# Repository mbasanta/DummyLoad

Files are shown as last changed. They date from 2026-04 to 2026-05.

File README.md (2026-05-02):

# DummyLoad

KiCad project for a 50 ohm RF dummy load board with integrated attenuation and rectified measurement output.

## Overview

This repository contains the schematic, PCB, custom footprint library, and generated manufacturing artifacts for the DummyLoad board.

From the schematic title block and notes:
- Design target: 50 ohm dummy load
- Rated power (design intent): 10 W
- Includes attenuation network:
  - Note in schematic: "40db Attenuation (use 3x 261 Ohm resistors for 30db)"
- Includes a rectified voltage measurement point for RF power estimation (see [Dummy Load Voltages](output/Dummy%20Load%20Voltages.pdf) for the relationship between rectified voltage and radio power output)

## Schematic

Schematic

## PCB

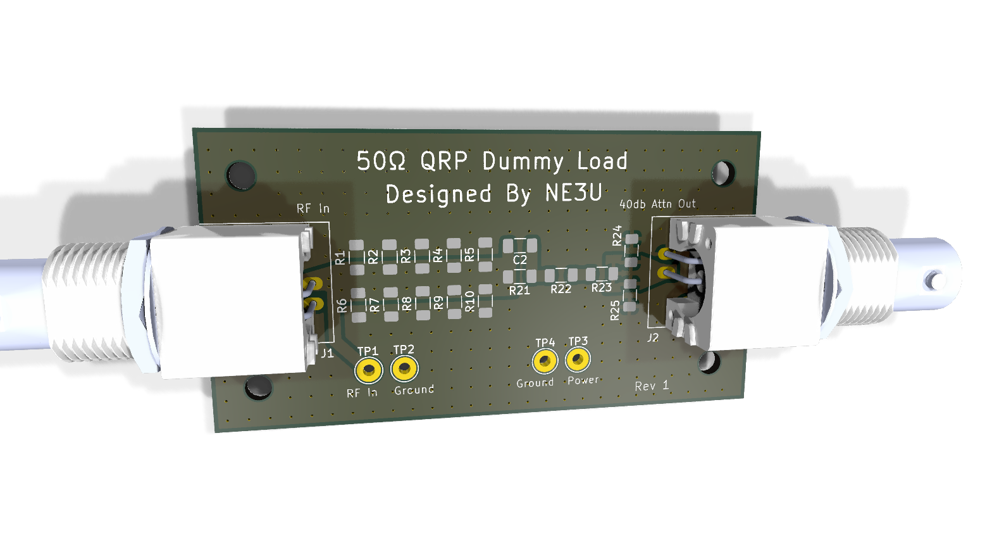
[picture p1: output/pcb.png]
PCB


## Main Files

- `DummyLoad.kicad_sch`: KiCad schematic
- `DummyLoad.kicad_pcb`: KiCad PCB layout
- `DummyLoad.kicad_pro`: KiCad project
- `MiscFootprints.pretty/`: Local footprint library used by this project
- `output/`: Generated artifacts (BOM, schematic PDF, Gerbers, drill files)
- `.github/workflows/kicad.yml`: CI workflow for ERC/DRC and artifact generation

## Connectors and Test Points

- `J1`: RF In (BNC horizontal)
- `J2`: RF Out (BNC horizontal)
- `TP1`: Power Out (rectified measurement output)
- `TP2`: GND

## Bill of Materials

A generated BOM is committed at:
- `output/bom.csv`

The CI workflow exports BOM fields:
- Reference
- Value
- Footprint
- Quantity
- DNP
- Mouser PN
- Datasheet

## Generated Manufacturing Outputs

When CI succeeds, generated files are updated in:
- `output/schematic.pdf`
- `output/bom.csv`
- `output/gerbers/`

These include copper, mask, silkscreen, fab, edge cuts, and drill outputs.

## CI / Automation

GitHub Actions workflow: `.github/workflows/kicad.yml`

It runs on pushes and pull requests to `main` (ignoring changes under `output/**`) and can also be triggered manually.

The workflow performs:
1. KiCad ERC
2. KiCad DRC
3. Schematic PDF export
4. BOM export
5. Gerber and drill export
6. Commit updated generated outputs on `main`
7. Upload production artifacts

## Working With the Project Locally

1. Open `DummyLoad.kicad_pro` in KiCad.
2. Ensure the local footprint library is available:
   - `MiscFootprints.pretty`
3. Run:
   - Schematic Editor ERC
   - PCB Editor DRC
4. Generate fabrication outputs from KiCad if needed.

## Safety and Validation Notes

This project handles RF power dissipation. Before physical use:
- Verify resistor power dissipation and thermal limits for your operating conditions.
- Validate attenuation and measurement calibration on your target frequency range.
- Confirm connector, PCB copper, and assembly choices meet your power and duty-cycle requirements.

## License

MIT. See `LICENSE`.

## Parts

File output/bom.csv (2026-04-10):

Refs | Value | Footprint | Qty | DNP | Mouser PN | Datasheet
C1 | 10nF | Capacitor_SMD:C_1206_3216Metric_Pad1.33x1.80mm_HandSolder | 1 |  | 77-VJ1206Y103JXAMP | https://www.vishay.com/docs/45199/vjcommercialseries.pdf
C2 | C | Capacitor_SMD:C_1206_3216Metric_Pad1.33x1.80mm_HandSolder | 1 | DNP |  | ~
D1 | 1N5711 | Diode_SMD:Nexperia_CFP3_SOD-123W | 1 |  | 621-1N5711W-F | https://www.mouser.com/datasheet/3/175/1/1N5711W.pdf
J1 | RF In | Connector_Coaxial:BNC_Amphenol_B6252HB-NPP3G-50_Horizontal | 1 |  | 737-RF101KD0050BKHDW | https://www.mouser.com/datasheet/3/6015/1/rf1_01k_d_00_50_bk_hdw_data_sheet.pdf
J2 | RF Out | Connector_Coaxial:BNC_Amphenol_B6252HB-NPP3G-50_Horizontal | 1 |  | 737-RF101KD0050BKHDW | https://www.mouser.com/datasheet/3/6015/1/rf1_01k_d_00_50_bk_hdw_data_sheet.pdf
R1 | 1K | Resistor_SMD:R_1206_3216Metric_Pad1.30x1.75mm_HandSolder | 1 |  | 71-RCS12061K00FKEA | https://www.vishay.com/docs/20065/rcse3.pdf
R2 | 1K | Resistor_SMD:R_1206_3216Metric_Pad1.30x1.75mm_HandSolder | 1 |  | 71-RCS12061K00FKEA | https://www.vishay.com/docs/20065/rcse3.pdf
R3 | 1K | Resistor_SMD:R_1206_3216Metric_Pad1.30x1.75mm_HandSolder | 1 |  | 71-RCS12061K00FKEA | https://www.vishay.com/docs/20065/rcse3.pdf
R4 | 1K | Resistor_SMD:R_1206_3216Metric_Pad1.30x1.75mm_HandSolder | 1 |  | 71-RCS12061K00FKEA | https://www.vishay.com/docs/20065/rcse3.pdf
R5 | 1K | Resistor_SMD:R_1206_3216Metric_Pad1.30x1.75mm_HandSolder | 1 |  | 71-RCS12061K00FKEA | https://www.vishay.com/docs/20065/rcse3.pdf
R6 | 1K | Resistor_SMD:R_1206_3216Metric_Pad1.30x1.75mm_HandSolder | 1 |  | 71-RCS12061K00FKEA | https://www.vishay.com/docs/20065/rcse3.pdf
R7 | 1K | Resistor_SMD:R_1206_3216Metric_Pad1.30x1.75mm_HandSolder | 1 |  | 71-RCS12061K00FKEA | https://www.vishay.com/docs/20065/rcse3.pdf
R8 | 1K | Resistor_SMD:R_1206_3216Metric_Pad1.30x1.75mm_HandSolder | 1 |  | 71-RCS12061K00FKEA | https://www.vishay.com/docs/20065/rcse3.pdf
R9 | 1K | Resistor_SMD:R_1206_3216Metric_Pad1.30x1.75mm_HandSolder | 1 |  | 71-RCS12061K00FKEA | https://www.vishay.com/docs/20065/rcse3.pdf
R10 | 1K | Resistor_SMD:R_1206_3216Metric_Pad1.30x1.75mm_HandSolder | 1 |  | 71-RCS12061K00FKEA | https://www.vishay.com/docs/20065/rcse3.pdf
R11 | 1K | Resistor_SMD:R_1206_3216Metric_Pad1.30x1.75mm_HandSolder | 1 |  | 71-RCS12061K00FKEA | https://www.vishay.com/docs/20065/rcse3.pdf
R12 | 1K | Resistor_SMD:R_1206_3216Metric_Pad1.30x1.75mm_HandSolder | 1 |  | 71-RCS12061K00FKEA | https://www.vishay.com/docs/20065/rcse3.pdf
R13 | 1K | Resistor_SMD:R_1206_3216Metric_Pad1.30x1.75mm_HandSolder | 1 |  | 71-RCS12061K00FKEA | https://www.vishay.com/docs/20065/rcse3.pdf
R14 | 1K | Resistor_SMD:R_1206_3216Metric_Pad1.30x1.75mm_HandSolder | 1 |  | 71-RCS12061K00FKEA | https://www.vishay.com/docs/20065/rcse3.pdf
R15 | 1K | Resistor_SMD:R_1206_3216Metric_Pad1.30x1.75mm_HandSolder | 1 |  | 71-RCS12061K00FKEA | https://www.vishay.com/docs/20065/rcse3.pdf
R16 | 1K | Resistor_SMD:R_1206_3216Metric_Pad1.30x1.75mm_HandSolder | 1 |  | 71-RCS12061K00FKEA | https://www.vishay.com/docs/20065/rcse3.pdf
R17 | 1K | Resistor_SMD:R_1206_3216Metric_Pad1.30x1.75mm_HandSolder | 1 |  | 71-RCS12061K00FKEA | https://www.vishay.com/docs/20065/rcse3.pdf
R18 | 1K | Resistor_SMD:R_1206_3216Metric_Pad1.30x1.75mm_HandSolder | 1 |  | 71-RCS12061K00FKEA | https://www.vishay.com/docs/20065/rcse3.pdf
R19 | 1K | Resistor_SMD:R_1206_3216Metric_Pad1.30x1.75mm_HandSolder | 1 |  | 71-RCS12061K00FKEA | https://www.vishay.com/docs/20065/rcse3.pdf
R20 | 1K | Resistor_SMD:R_1206_3216Metric_Pad1.30x1.75mm_HandSolder | 1 |  | 71-RCS12061K00FKEA | https://www.vishay.com/docs/20065/rcse3.pdf
R21 | 820 | Resistor_SMD:R_1206_3216Metric_Pad1.30x1.75mm_HandSolder | 1 |  | 279-CRGH1206F820R | https://www.te.com/commerce/DocumentDelivery/DDEController?Action=srchrtrv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
R22 | 820 | Resistor_SMD:R_1206_3216Metric_Pad1.30x1.75mm_HandSolder | 1 |  | 279-CRGH1206F820R | https://www.te.com/commerce/DocumentDelivery/DDEController?Action=srchrtrv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
R23 | 820 | Resistor_SMD:R_1206_3216Metric_Pad1.30x1.75mm_HandSolder | 1 |  | 279-CRGH1206F820R | https://www.te.com/commerce/DocumentDelivery/DDEController?Action=srchrtrv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
R24 | 102 | Resistor_SMD:R_1206_3216Metric_Pad1.30x1.75mm_HandSolder | 1 |  | 667-ERJ-8ENF1020V | https://industrial.panasonic.com/cdbs/www-data/pdf/RDO0000/RDO0000C334.pdf
R25 | 102 | Resistor_SMD:R_1206_3216Metric_Pad1.30x1.75mm_HandSolder | 1 |  | 667-ERJ-8ENF1020V | https://industrial.panasonic.com/cdbs/www-data/pdf/RDO0000/RDO0000C334.pdf
R26 | 100K | Resistor_SMD:R_1206_3216Metric_Pad1.30x1.75mm_HandSolder | 1 |  | 652-CRM1206QFX-1003E | https://www.mouser.com/catalog/specsheets/Bourns_1-11-2023_CRM-Q_datasheet.pdf
TP1 | RF In | TestPoint:TestPoint_THTPad_D3.0mm_Drill1.5mm | 1 |  |  | ~
TP2 | GND | TestPoint:TestPoint_THTPad_D3.0mm_Drill1.5mm | 1 |  |  | ~
TP3 | Power Out | TestPoint:TestPoint_THTPad_D3.0mm_Drill1.5mm | 1 |  |  | ~
TP4 | GND | TestPoint:TestPoint_THTPad_D3.0mm_Drill1.5mm | 1 |  |  | ~

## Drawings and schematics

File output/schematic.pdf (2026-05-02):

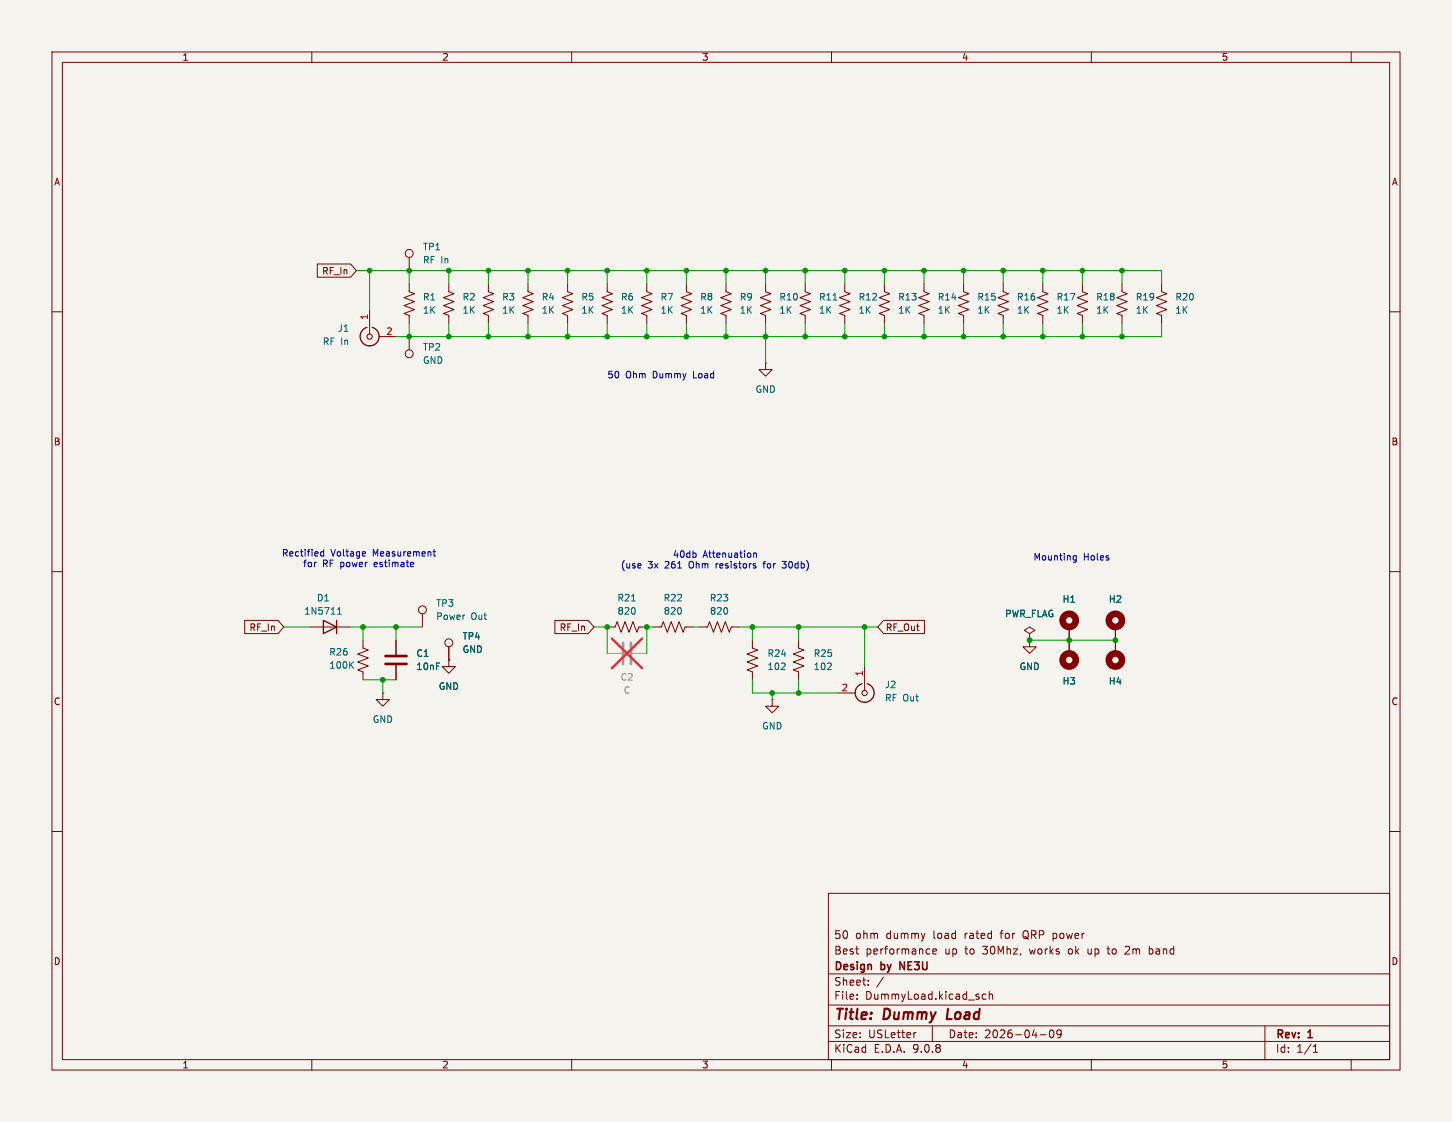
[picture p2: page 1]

for RF power estimate

Id: 1/1 Title: Dummy Load

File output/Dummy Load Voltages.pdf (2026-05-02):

## Dummy Load Power Output

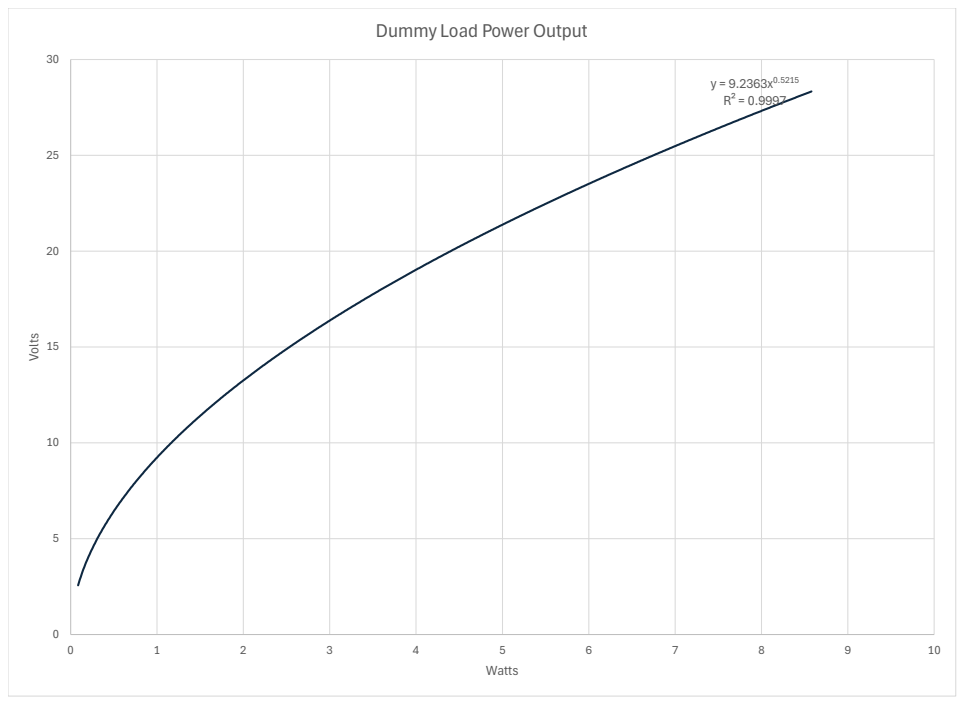
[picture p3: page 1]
Volts; Watts

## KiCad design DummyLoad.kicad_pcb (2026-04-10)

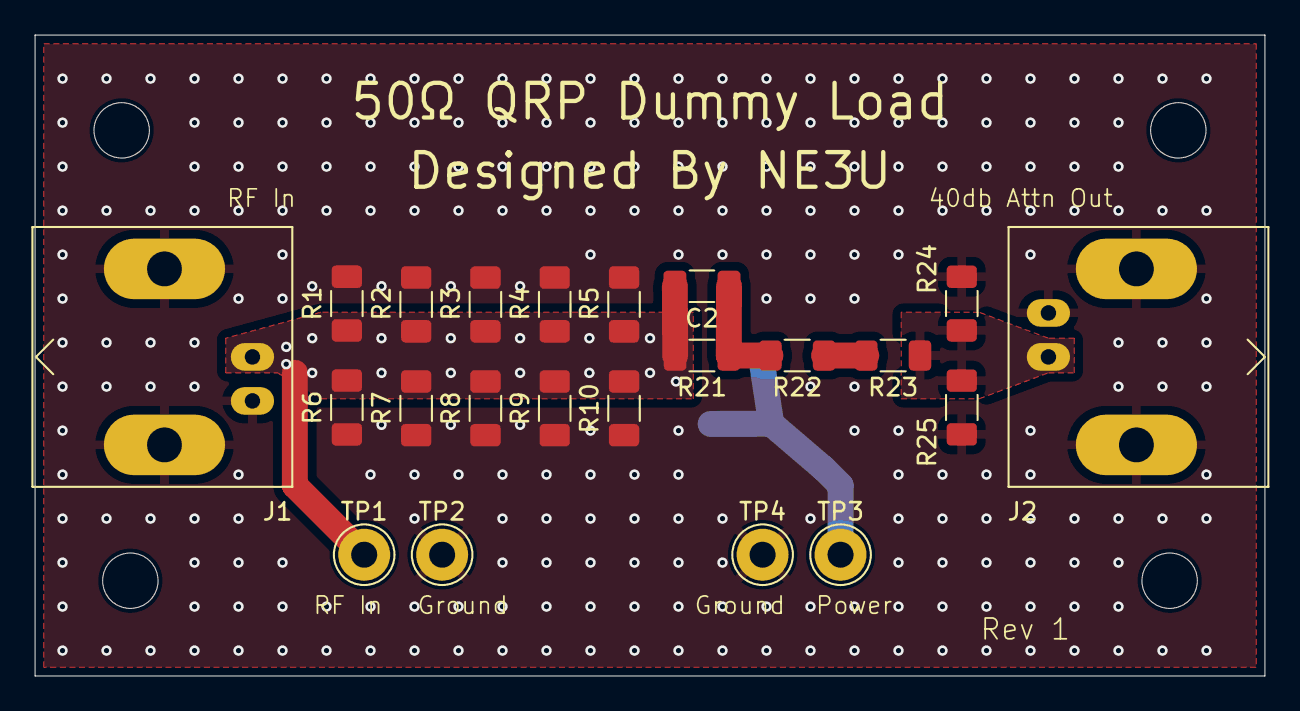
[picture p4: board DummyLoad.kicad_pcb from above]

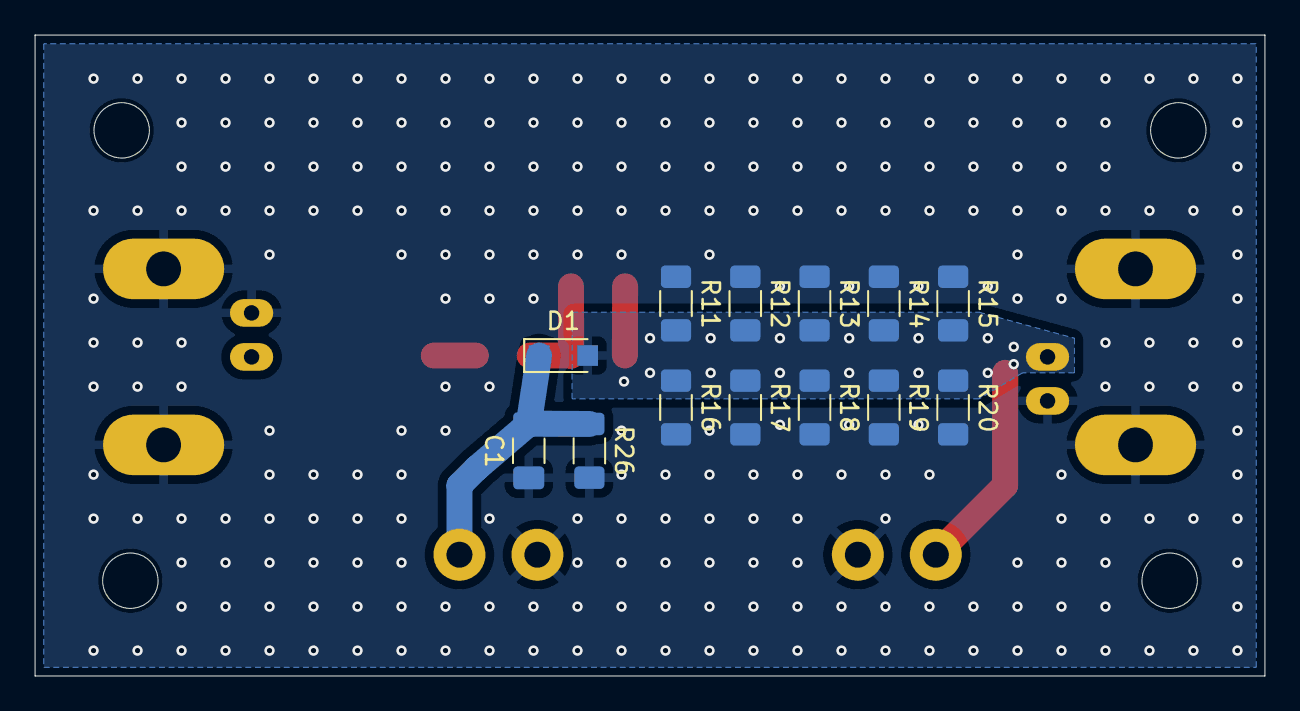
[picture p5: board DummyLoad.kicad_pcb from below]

Board: 2 copper layers, 71.0 x 37.0 mm, 39 parts (13 on the bottom side), 6 nets.

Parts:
C1: 10nF; C_1206_3216Metric_Pad1.33x1.80mm_HandSolder
C2: C; C_1206_3216Metric_Pad1.33x1.80mm_HandSolder
D1: 1N5711; Nexperia_CFP3_SOD-123W
H1, H2, H3, H4: MountingHole_Pad; MountingHole_3.2mm_M3
J1: RF In; BNC_Amphenol_B6252HB-NPP3G-50_Horizontal
J2: RF Out; BNC_Amphenol_B6252HB-NPP3G-50_Horizontal
R1, R2, R3, R4, R5, R6, R7, R8, R9, R10, R11, R12, R13, R14, R15, R16, R17, R18, R19, R20: 1K; R_1206_3216Metric_Pad1.30x1.75mm_HandSolder
R21, R22, R23: 820; R_1206_3216Metric_Pad1.30x1.75mm_HandSolder
R24, R25: 102; R_1206_3216Metric_Pad1.30x1.75mm_HandSolder
R26: 100K; R_1206_3216Metric_Pad1.30x1.75mm_HandSolder
TP1: RF In; TestPoint_THTPad_D3.0mm_Drill1.5mm
TP2, TP4: GND; TestPoint_THTPad_D3.0mm_Drill1.5mm
TP3: Power Out; TestPoint_THTPad_D3.0mm_Drill1.5mm

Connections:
GND: C1.2, J1.2 (Ext), J2.2 (Ext), R1.2, R2.2, R3.2, R4.2, R5.2, R6.2, R7.2, R8.2, R9.2, R10.2, R11.2, R12.2, R13.2, R14.2, R15.2, R16.2, R17.2, R18.2, R19.2, R20.2, R24.2, R25.2, R26.2, TP2.1, TP4.1
unnamed: C2.1, R21.1, R22.2
unnamed: C1.1, D1.1 (K), R26.1, TP3.1
unnamed: R22.1, R23.2
RF_In: C2.2, D1.2 (A), J1.1 (In), R1.1, R2.1, R3.1, R4.1, R5.1, R6.1, R7.1, R8.1, R9.1, R10.1, R11.1, R12.1, R13.1, R14.1, R15.1, R16.1, R17.1, R18.1, R19.1, R20.1, R21.2, TP1.1
RF_Out: J2.1 (In), R23.1, R24.1, R25.1

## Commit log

2026-03-24 Add DummyLoad KiCad project and footprints
    Add a new KiCad project for a DummyLoad: DummyLoad.kicad_pcb, DummyLoad.kicad_pro, and DummyLoad.kicad_sch. Includes PCB layout with BNC connector, resistor footprints, mounting holes and pin header;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
    [DummyLoad.kicad_pcb, DummyLoad.kicad_sch]
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2026-03-24 Modify production file paths in kicad.yml
    Updated file paths for production files in KiCad workflow.
2026-03-24 Schematic: add symbols, ground & rewire
    Modify DummyLoad.kicad_sch: add new symbols and power net, reposition several components and update wiring/junctions. Added Device:R_US instances (R24, R23), a power:GND symbol that creates a global 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
    [DummyLoad.kicad_sch]
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2026-03-24 chore(kicad): update generated outputs [skip ci]
2026-03-24 Update .gitignore to remove BOM file exclusions
    Remove BOM file patterns from .gitignore
2026-03-24 Add BOM fields and labels to KiCad workflow
2026-03-24 Fix BOM fields and labels formatting in kicad.yml
2026-03-24 Refactor KiCad GitHub Actions workflow
    Updated KiCad workflow to improve output handling and error checking.
2026-03-24 Update KiCad GitHub Actions workflow
    Updated KiCad workflow to use actions/checkout@v6 and modified output file handling.
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2026-03-24 Disable DRC check in kicad.yml
    Temporarily disable DRC check in KiCad workflow.
2026-03-24 Remove drill output from workflow
    Removed drill directory from output copying and git add.
2026-03-24 Schematic: update layout & title block
    Set paper to USLetter and add a title block (title, date, revision, company and descriptive comments). Perform a large schematic redraw: many junctions, wires and their coordinates were moved and mul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
    [DummyLoad.kicad_sch]
2026-03-26 Refactor connector, testpoints and layout
    Replace generic connector symbols with coaxial/TestPoint symbols and tidy schematic metadata; adjust component positions, wires and junctions, and update footprints/datasheets/Mouser PNs. Added text annotations (Mounting Holes, 50 Ohm Dummy Load, attenuation/measurement notes), new testpoint symbols/instances and a few resistor symbols/instances, renamed/updated some references (e.g. R24 -> R26) and moved mounting holes and global label locations to match the revised layout. These changes improve part accuracy, footprints and documentation in the DummyLoad.kicad_sch.
    [DummyLoad.kicad_sch]
2026-03-26 Add THT test point footprints to schematic
    Assign the TestPoint footprint to two components in DummyLoad.kicad_sch. Previously the Footprint property was empty; this commit sets it to "TestPoint:TestPoint_THTPad_D1.0mm_Drill0.5mm" for the two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
    [DummyLoad.kicad_sch]
2026-03-26 Update component datasheets, PNs, footprints
    Update metadata in DummyLoad.kicad_sch: replace generic Vishay datasheet links with the direct rcse3.pdf URL and change Mouser PN from 279-CRGP2512F1K0 to 71-RCS12061K00FKEA across multiple components. Also update one diode entry: change footprint to Diode_SMD:Nexperia_CFP3_SOD-123W, datasheet to 1N5711W.pdf, and Mouser PN to 621-1N5711W-F. These changes correct BOM/reference links and footprints for accurate sourcing.
    [DummyLoad.kicad_sch]
2026-03-26 Update PCB footprints, add test points and enable DRC
    Enable run_drc in the GitHub workflow and apply extensive footprint changes in DummyLoad.kicad_pcb: add THT test points, convert multiple resistors from 2512 to 1206 footprints (position/size/pad updates and 3D model path changes), update connector metadata (datasheet and Mouser PN), adjust mounting hole/testpoint footprints and silkscreen/pad geometry, and add part metadata (Mouser PNs, datasheet links, zone_connect). These edits correct footprint footprints/metadata and prepare the board for DRC and gerber generation.
    [DummyLoad.kicad_pcb]
2026-03-26 Add README for DummyLoad KiCad project
    Add a comprehensive README documenting the DummyLoad KiCad project: design targets (50 Ω dummy load, 10 W), included files (schematic, PCB, footprints, outputs), connectors/test points, BOM location,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
2026-03-26 Change diode value to 1N5711
    Update the diode 'Value' property from 1N4004 to 1N5711 in both the KiCad schematic and PCB files (DummyLoad.kicad_sch and DummyLoad.kicad_pcb) so the schematic and board reflect the new component se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
    [DummyLoad.kicad_pcb, DummyLoad.kicad_sch]
2026-03-26 Upload KiCad ERC/DRC diagnostics on failure
    When the KiCad production step fails, collect common ERC/DRC/report/log files from the workspace into a diagnostics/ directory and upload them as an artifact (actions/upload-artifact@v7). Uses a find+cp --parents loop and set -euo pipefail to safely gather files. Also updates the verify step to use the same conditional (always() && steps.production.outcome != 'success') so the workflow stops after diagnostics are captured. This helps with debugging KiCad ERC/DRC failures by preserving relevant logs and reports.
2026-03-26 Remove generated gerber output files
    Delete generated DummyLoad gerber and drill outputs under output/gerbers (including nested output/gerbers/gerbers). These are PCB fabrication artifacts (Gerber, drill, job files) and are being removed from source control to avoid tracking generated build artifacts.
    [DummyLoad-B_Courtyard.gbr, DummyLoad-B_Cu.gbl, DummyLoad-B_Fab.gbr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]
2026-03-26 Copy gerbers to output and ignore .DS_Store
    Update CI workflow to copy the gerbers into the output directory (changed cp target from output/gerbers to output) so generated artifacts are placed directly under output. Also add .DS_Store to .giti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
2026-03-26 Update KiCad workflow and remove generated gerbers
    Add an explicit pcb_output_layers setting to .github/workflows/kicad.yml to control which PCB layers are exported by the KiCad CI step. Remove a large set of generated gerber/drill files from output/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
    [DummyLoad-B_Courtyard.gbr, DummyLoad-B_Cu.gbl, DummyLoad-B_Fab.gbr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]
2026-03-26 Update DummyLoad.kicad_pcb polygon coords
    Adjust polygon and filled_polygon vertex coordinates in DummyLoad.kicad_pcb (F.Cu and B.Cu). Fixes corner vertex from x=168.5 to x=169 and normalizes several numeric precision values (e.g. 168.874259 -> 168.8755 and related small coordinate tweaks) to align edges and unify coordinate precision.
    [DummyLoad.kicad_pcb]
2026-03-28 Add BNC STEP model and update PCB
    Add 3dShapes/CONBNC002.stp — a STEP AP214 3D model (exported from SolidWorks 2021) for the BNC connector. Also update DummyLoad.kicad_pcb to reference the new 3D model so the connector is available f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
    [DummyLoad.kicad_pcb]
2026-03-28 Adjust BNC connector 3D model and pad UUIDs
    Update BNC connector footprint: set reference rotation from 180 to 0, add CONBNC002.stp 3D model with offset (0, 5.1, 0) and rotation (-90, 0, -180), and replace two pad UUIDs with new unique values. These changes fix silkscreen orientation, include a STEP model for mechanical visualization, and resolve duplicated UUIDs.
    [DummyLoad.kicad_pcb]
2026-03-29 Enable SVG outputs in KiCad workflow
    Add schematic_output_svg: true and pcb_output_svg: true to the .github/workflows/kicad.yml so the CI generates SVG exports for schematics and PCBs. This enables producing visual artifacts useful for 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
2026-03-29 Include SVG outputs in CI artifacts
    Copy schematic and PCB SVGs into the output directory and include them in the committed/uploaded artifacts. The workflow now copies schematics/DummyLoad.svg -> output/schematic.svg and pcb.svg -> out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
2026-03-29 Use PNG for PCB output in CI workflow
    Switch the KiCad GitHub Actions workflow to produce PCB output as an image (png) instead of SVG by enabling pcb_output_image and updating file copy/upload steps. Adjusted artifact paths and collectio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
2026-03-29 Update KiCad workflow outputs; remove pcb.svg
    Add additional PCB image outputs in .github/workflows/kicad.yml (pcb_output_image_floor and pcb_oupput_image_perspective), update artifact staging to add output/pcb.png instead of output/pcb.svg, and remove the now-deleted output/pcb.svg file. Note: the workflow key 'pcb_oupput_image_perspective' appears to be misspelled and may need correction.
2026-04-07 Add schematic SVG and pcb.png images to README
    Agent-Logs-Url: https://github.com/mbasanta/DummyLoad/sessions/f675b0ef-5048-4c67-9bc1-c7e1d741e8dc
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2026-04-09 Enlarge THT test points and update PCB layout
    Replace TP1/TP2 footprints with larger THT test points (TestPoint_THTPad_D3.0mm_Drill1.5mm): pad sizes and drill diameters increased from 1.0/0.5mm to 3.0/1.5mm, and related silk/fab text positions and silk radii adjusted. Many via coordinates and UUIDs were updated/refreshed, and a few silkscreen text anchors ("Power", "Ground") were nudged. DummyLoad.kicad_sch was also modified alongside these PCB changes. Reason: accommodate larger test probes and tidy up PCB placement/identifiers.
    [DummyLoad.kicad_pcb, DummyLoad.kicad_sch]
2026-04-09 Use hand-solder 1206 resistor footprints
    Replace Resistor_SMD:R_1206_3216Metric with R_1206_3216Metric_Pad1.30x1.75mm_HandSolder across the PCB. Pads enlarged from 1.125x1.75 to 1.30x1.75 (adjusted roundrect ratio) and pad positions/rotations slightly tweaked; courtyard/silkscreen lines and text orientations updated. UUIDs and metadata/tags/descriptions updated, and zone_connect attributes removed where present. These changes provide elongated pads for easier hand-soldering and consistent footprint metadata.
    [DummyLoad.kicad_pcb, DummyLoad.kicad_sch]
2026-04-09 Set zone_connect and fix text rotations
    Add zone_connect 2 to multiple SMD footprints/pads and components to enable zone connectivity. Update many property and fp_text rotations from 270° to 90° to correct silkscreen/fab text orientation. Also includes board/footprint geometry adjustments (likely auto-generated by KiCad/footprint tool).
    [DummyLoad.kicad_pcb]
2026-04-10 Add TH testpoints and update PCB labels/layout
    Add two through-hole testpoint footprints (RF In and GND) and reassign existing testpoint references (TP1/TP2 -> TP3/TP4). Adjusted testpoint coordinates and nets, updated multiple silkscreen texts (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
    [DummyLoad.kicad_pcb, DummyLoad.kicad_sch]
2026-04-10 Update schematic metadata and pin UUID
    Bump sheet date and revision, refine title-block comments to note best performance up to 30MHz and a QRP power rating, and correct a pin UUID (...29e -> ...29f). Documentation and identifier cleanup in DummyLoad.kicad_sch.
    [DummyLoad.kicad_sch]
2026-04-10 Adjust PCB testpoints, silks and via positions
    Update DummyLoad.kicad_pcb: shift two THT testpoint footprints (TP1, TP2) and nudge silk labels ("RF In", "Ground"). Repositioned many vias across the board and regenerated their UUIDs to match the n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
    [DummyLoad.kicad_pcb]
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2026-04-10 Fix rotation angle for PCB output image
2026-04-10 Fix rotation angle in KiCad workflow
2026-04-10 Correct pcb_output_image_perspective and rotation
    Fix typo in pcb_output_image_perspective and update rotation values.
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2026-05-02 Add dummy load voltages PDF and update README
    Add output/Dummy Load Voltages.pdf documenting the relationship between rectified voltage and radio power output, and update README to reference the new PDF for details on the rectified voltage measu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
